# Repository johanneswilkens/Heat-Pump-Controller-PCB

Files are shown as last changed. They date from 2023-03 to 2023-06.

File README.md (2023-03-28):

# Heat Pump Controller PCB

This project is a versatile controller board designed primarily for LG Therma V heat pumps, but it may work with other systems as well. With Modbus and OpenTherm slave support, PWM input and output for a waterpump, multiple relays, and several input/output options, this board can help make the heat pump more efficient and make it easy to adjust heating curves and other settings.

This board can be programmed using the Arduino IDE or EspHome, which makes it easy to integrate with home automation systems like Home Assistant. With some modifications, the following code can run on it: https://github.com/altrnate32/esp-lg-control

In addition to the base features, this board includes several optional features, such as an isolated I2C interface, isolated UART, 5V UART, onboard temperature and humidity sensors, and a status LED. With these optional features, this board can be customized to suit a wide range of applications.

## Features

The following features are included in this controller board:

- Modbus and OpenTherm slave support
- PWM input and output for a waterpump
- 4 relays (can operate 230V AC 3A. For higher current, up to 10A PCB tracks must be reinforced with soldered on wire of sufficient cross section)
- 2 outputs that can work as high-side or low-side switches at 5V or 12V (via on board voltage converters)
- 2 inputs supporting 5V or 12V
- 4 connectors for DS18B20 sensors (several sensors can be connected to one connector)
- Optional isolated I2C interface
- Optional isolated UART
- Optional 5V UART
- Optional onboard DS18B20 and SHT40 sensor
- WS2812 LED for showing status (or regular LED if you dont need RGB)
- Powered via USB-C

## Project Status
- [x] Tested stable operation. 
- [x] Tested with LG Therma V HM143MR.U34 (14 kW three phase monoblock)
- [ ] Test on other devices
- [ ] Modify PCB for release
- [ ] Create Wiki Page

## Getting Started

To get started with this controller board, follow these steps:

1. Obtain the PCB files from the GitHub repository.
2. Use a PCB manufacturing service to manufacture the board or assemble the board yourself by soldering the components onto the board.
3. Program the ESP32 microcontroller using the Arduino IDE or other compatible software, such as Esphome. If you want to control your heat pump with Home Assistant, you can use Esphome to easily integrate the controller with Home Assistant.
4. Connect the heat pump components and other pheripherals to the appropriate connectors on the board. Make sure you use the correct connectors.
5. Power on the board using a USB-C cable.

## IO reference

| Function | ESP32 GPIO Pin |
|---|---|
| Input1 | GPIO36 |
| Input2 | GPIO39 |
| Output1 | GPIO25 |
| Output2 | GPIO26 |
| Relay1 | GPIO27 |
| Relay2 | GPIO14 |
| Relay3 | GPIO12 |
| Relay4 | GPIO13 |
| Pump PWM In | GPIO35 |
| Pump PWM Out | GPIO32 |
| Open Therm In | GPIO34 |
| Open Therm Out | GPIO33 |
| Modbus RX | GPIO16 |
| Modbus TX | GPIO17 |
| Modbus Flow Control | GPIO5 |
| LED | GPIO23 |
| DS18B20 | GPIO15 |
| UART_ISO RX | GPIO19 |
| UART_ISO TX | GPIO18 |
| UART_5V RX | GPIO2 |
| UART_5V TX | GPIO4 |
| I2C SDA | GPIO21 |
| I2C SCL | GPIO22 | 

## Donating

If you find this project useful and would like to support its development, you can donate to the project using [the Ko-fi donating platform](https://ko-fi.com/johanneswilkens). Your donation will help cover the costs of developing and testing the board, as well as maintaining the project repository and providing support to users.



## Support and feedback

If you need help with this project, or have any suggestions, please open an issue on the GitHub repository.

## License

This work is licensed under a
[Creative Commons Attribution-NonCommercial-ShareAlike 4.0 International License][cc-by-nc-sa].

[][cc-by-nc-sa]

[cc-by-nc-sa]: http://creativecommons.org/licenses/by-nc-sa/4.0/
[cc-by-nc-sa-image]: https://licensebuttons.net/l/by-nc-sa/4.0/88x31.png
[cc-by-nc-sa-shield]: https://img.shields.io/badge/License-CC%20BY--NC--SA%204.0-lightgrey.svg

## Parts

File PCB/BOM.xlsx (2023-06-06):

Designator | Footprint | Quantity | Value | Example LCSC Part #
C1, C2, C21, C23, C24, C5, C6, C7, C9 | 0603 | 9 | 100nF | C77055
C10, C14, C18, C20 | 0805 | 4 | 22uF | C86816
C11, C13, C19 | 1206 | 3 | 100uF | C312983
C12, C4 | 0805 | 2 | 10uF | C84416
C15 | 0603 | 1 | 8.2nF | C469537
C16 | 0603 | 1 | 10pF | C470847
C17 | 0603 | 1 | 1nF | C77026
C22, C3 | 0805 | 2 | 1uF | C77083
C8 | 0603 | 1 | 4.7nF | C85980
D1 | SOT-23 | 1 | SM712_SOT23 | C5180237
D10 | SOT-23 | 1 | BAT54W | C5261070
D11, D12, D4, D5 | D_SOD-123 | 4 | 1N4448W | C64898
D13 | LED_WS2812B-2020_PLCC4_2.0x2.0mm | 1 | WS2812-2020 | C965555
D14, D15, D16, D17, D18, D19, D20, D21, D22, D23, D7, D2 | 0603 | 12 | LED | C72041
D6, D8, D9 | D_SMA | 3 | SS34 | C2836396
F2 | 1206 | 1 | Polyfuse 0.75A holding - 1.5A trip | C269117
J1, J10, J11, J12, J19, J22, J23, J7, J8, J9 | KF141V-2.54-3P | 10 | KEFA KF141V-2.54-3P | C475115
J14, J15, J16 | JST_XH_B4B-XH-A_1x04_P2.50mm_Vertical | 3 | JST XH B4B | C144395
J17, J18, J3, J4 | KF142V-5.08-3P | 4 | KEFA KF142V-5.08-3P | C475135
J2 | USB_C_Receptacle_HRO_TYPE-C-31-M-12 | 1 | USB_C_Receptacle | C2988369
J6 | KF141V-2.54-2P | 1 | KEFA KF141V-2.54-2P | C475114
K1, K2, K3, K4 | Relay_SPDT_SANYOU_SRD_Series_Form_C | 4 | SONGLE SRD-05VDC-SL-C | C30431
L1, L3 | L_Bourns_SRP7028A_7.3x6.6mm | 2 | 22uH | C5189963
L2 | L_Bourns-SRN8040_8x8.15mm | 1 | 3.6uH | C168119
Q1 | SOT-363_SC-70-6 | 1 | UMH3N | C62892
Q10, Q11, Q12, Q13, Q19, Q2, Q20, Q22, Q3, Q5, Q8 | SOT-23 | 11 | BC847 | C426568
Q14, Q21, Q4, Q6, Q7, Q9 | SOT-23 | 6 | BC857 | C5204724
R1, R3 | 0603 | 2 | 680R | C112310
R10, R17, R18, R19, R20, R35, R39, R4, R40, R41, R46, R47, R48, R49, R5, R52, R53, R6, R62, R63, R64, R67, R68, R69, R7, R70, R71, R8, R9, R23 | 0603 | 29 | 10k | C98220
R11, R27 | 0603 | 1 | 470R | C114669
R12, R13 | 0603 | 2 | 220R | C107696
R14, R15 | 0603 | 2 | 5k1 | C105580
R16 | 0603 | 1 | 1M | C105578
R2 | 0603 | 1 | 130R | C141677
R21, R28 | 0603 | 2 | 270k | C137754
R22, R32, R42, R43, R44 | 0603 | 5 | 4k7 | C99782
R24 | 0603 | 1 | 6k8 | C114632
R25 | 0603 | 1 | 36k | C114619
R26 | 0603 | 1 | 2k7 | C114612
R29 | 0603 | 1 | 15k | C114661
R30 | 0603 | 1 | 100r | C105588
R31 | 0603 | 1 | 39r | C137733
R33 | 0603 | 1 | 33k | C126359
R34, R45 | 0603 | 2 | 20k | C105575
R36 | 0603 | 1 | 1k | C22548
R37, R38, R50, R51, R65, R66 | 0603 | 6 | 47k | C105579
R54, R55, R56, R57 | 0603 | 4 | 820R | C114638
R58, R59, R60, R61, R72, R73, R74 | 0603 | 7 | 390R | C114620
SW1 | SW_SPST_SKQG_WithStem | 1 | TS-1187A-C-C-B | C318889
U1 | SOIC-8_3.9x4.9mm_P1.27mm | 1 | MAX3485 | C695837
U10 | VSSOP-8_2.4x2.1mm_P0.5mm | 1 | TXB0102DCU | C60709
U11 | SOIC-8_3.9x4.9mm_P1.27mm | 1 | ISO7721 | C366164
U12 | Sensirion_DFN-4_1.5x1.5mm_P0.8mm_SHT4x_NoCentralPad | 1 | SHT4x | C2909890
U13 | TO-92_Inline | 1 | DS18B20 | C376006
U2 | ESP32-WROOM-32 | 1 | ESP32-WROOM-32 | C701342
U3 | SOIC-16_3.9x9.9mm_P1.27mm | 1 | CH340C | C84681
U4 | SOT-23-6 | 1 | USBLC6-2SC6 | C5180249
U5, U7 | SOT-23-6 | 2 | MT3608 | C84817
U6 | TI_SO-PowerPAD-8_ThermalVias | 1 | TPS54331 | C9865
U8 | SOIC-8_3.9x4.9mm_P1.27mm | 1 | DS18B20Z | C695837
U9 | SOIC-8_3.9x4.9mm_P1.27mm | 1 | ISO1540 | C179739

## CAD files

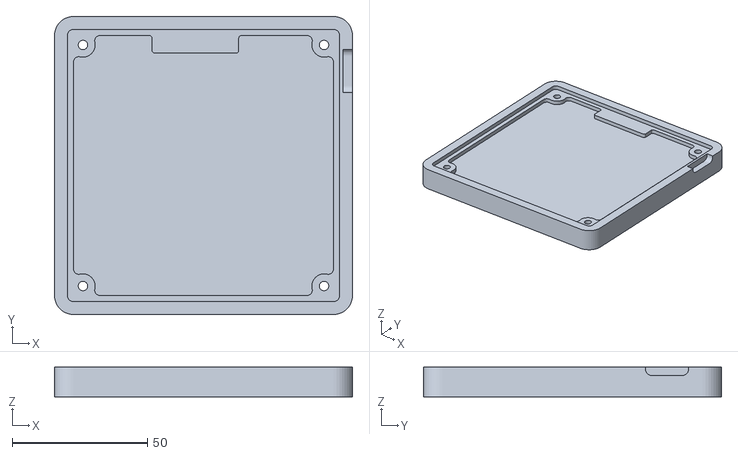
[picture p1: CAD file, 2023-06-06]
Case/Basic case.stl
110.0 x 110.0 x 11.0

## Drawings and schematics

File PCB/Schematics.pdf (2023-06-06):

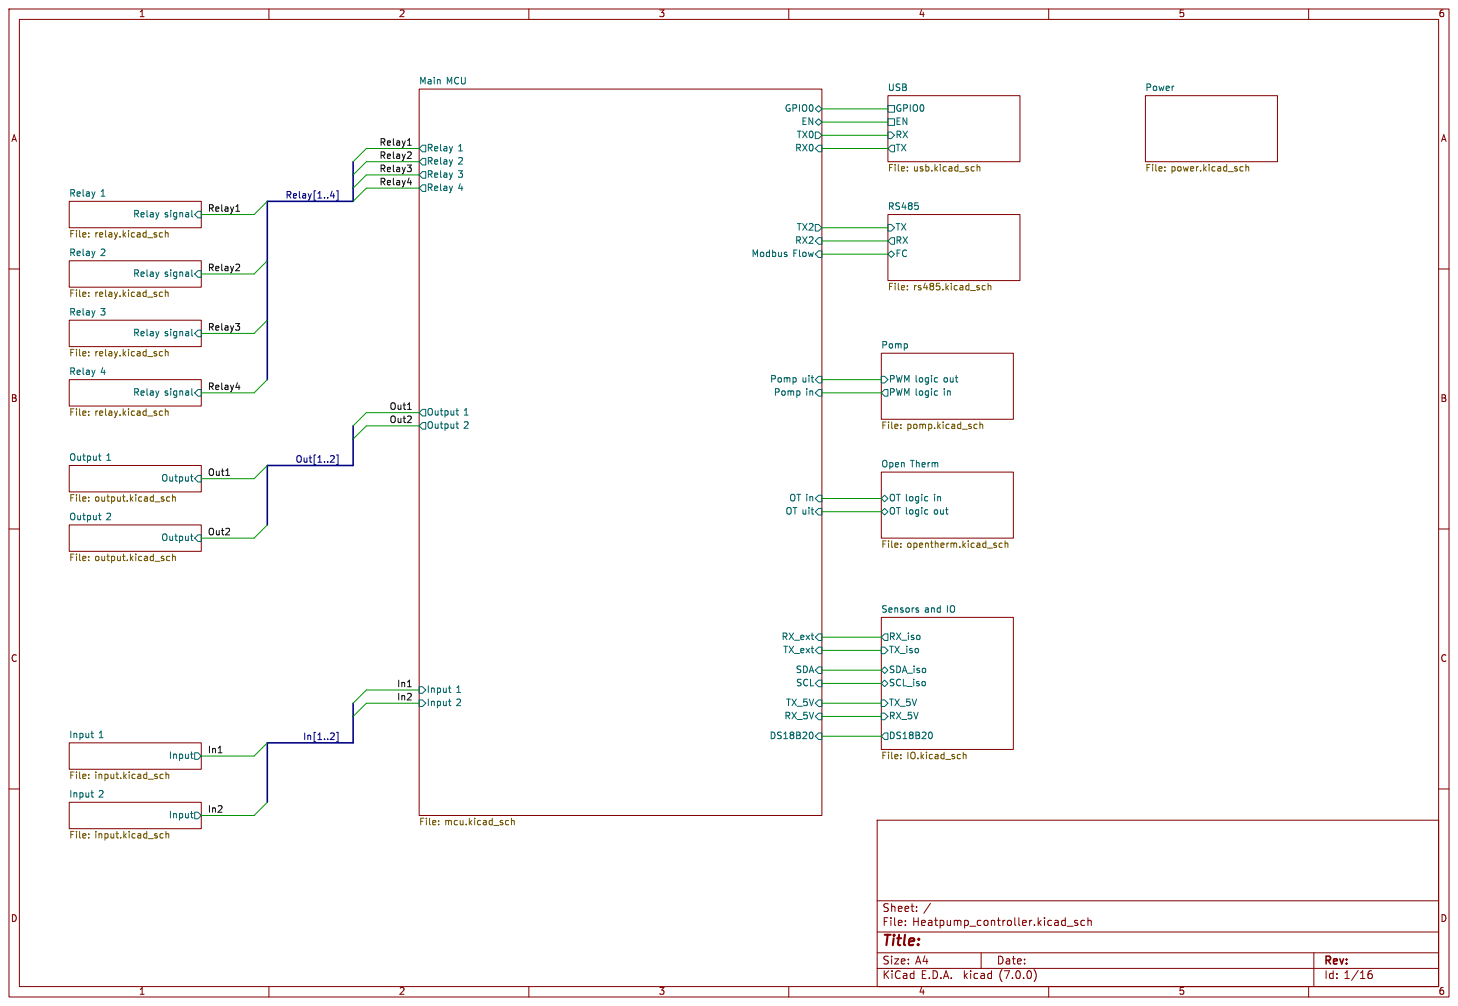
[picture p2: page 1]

Power File: power.kicad_sch EN

TX0 GPIO0 RX0 TX2 RX2 Relay 2 Relay 1 Relay 3 Relay 4 Output 1 Output 2

Pomp in OT uit OT in Pomp uit DS18B20 TX_ext RX_ext RX_5V

Id: 1/16 Title: File: Heatpump_controller.kicad_sch Sheet: /

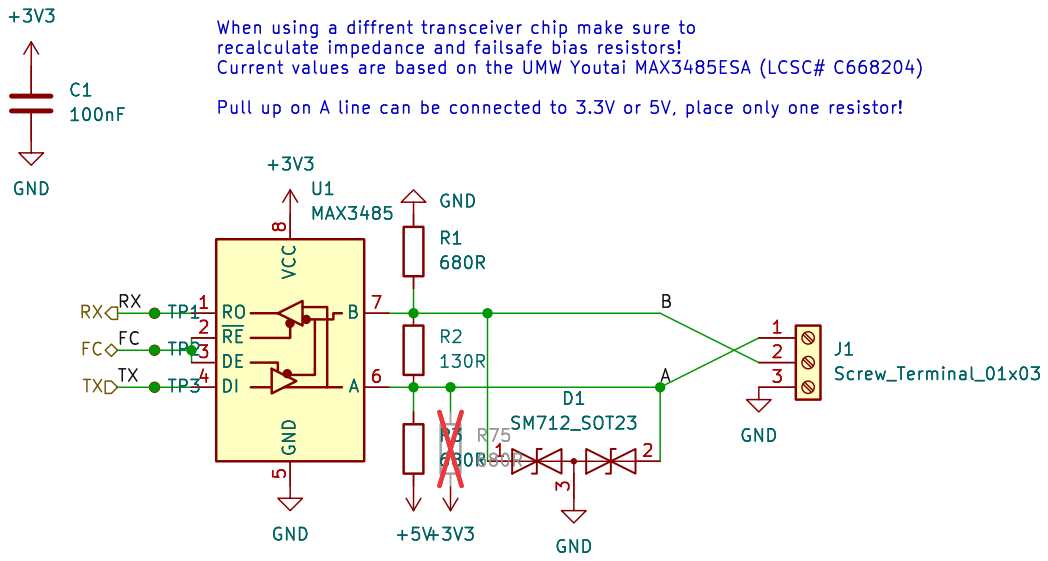
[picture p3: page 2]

Id: 2/16 Title: File: rs485.kicad_sch Sheet: /RS485/ GND

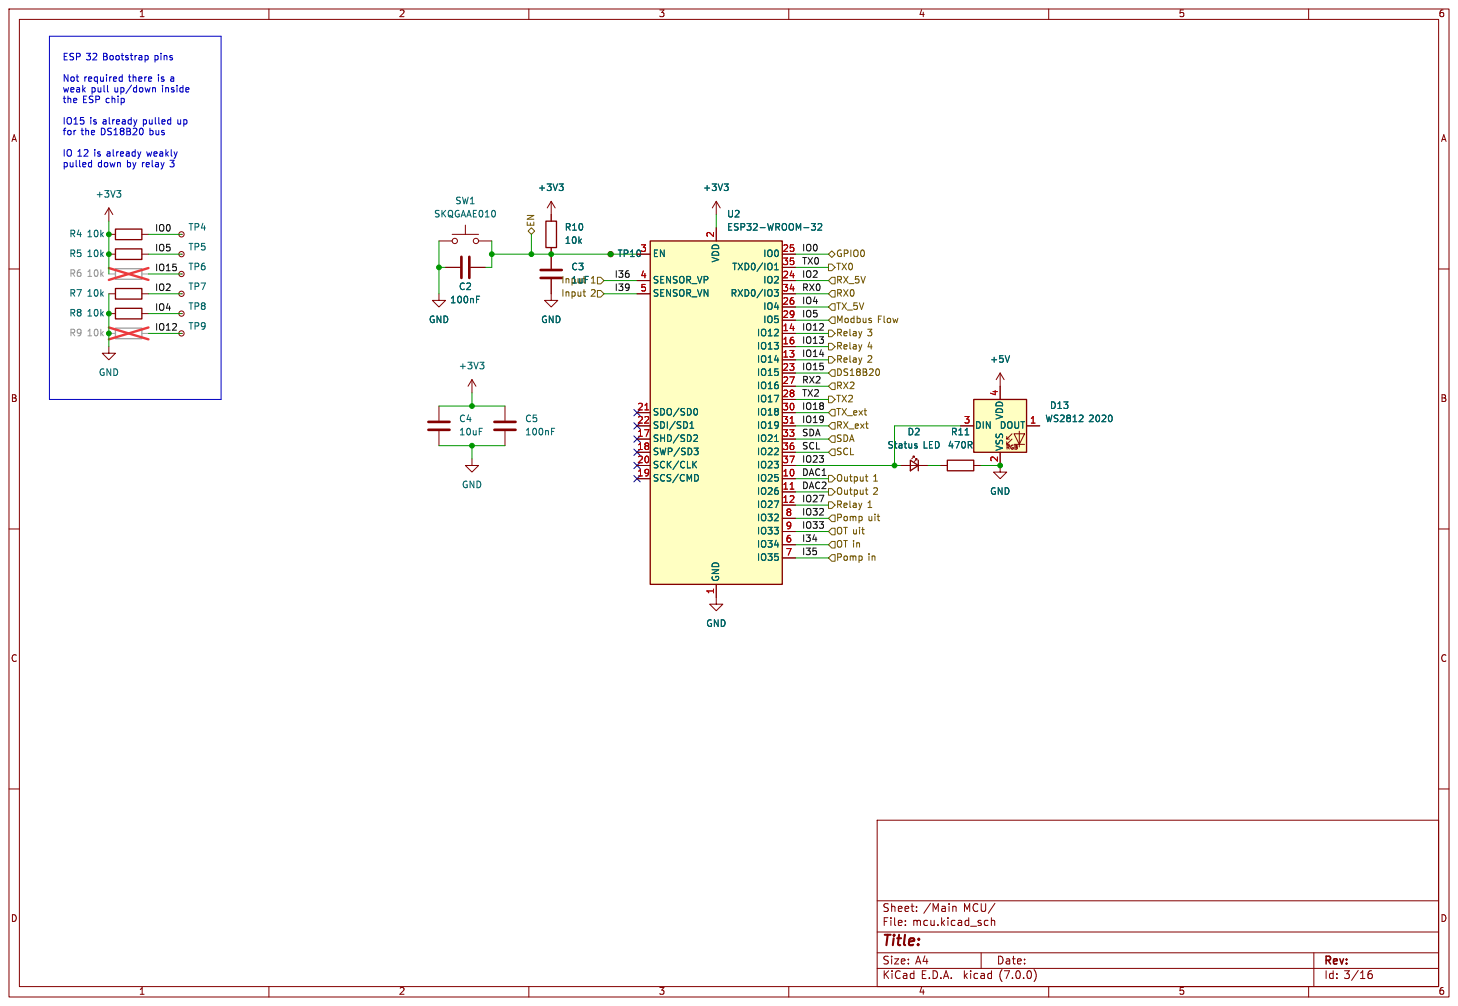
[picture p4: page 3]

IO15 is already pulled up
for the DS18B20 bus

IO 12 is already weakly

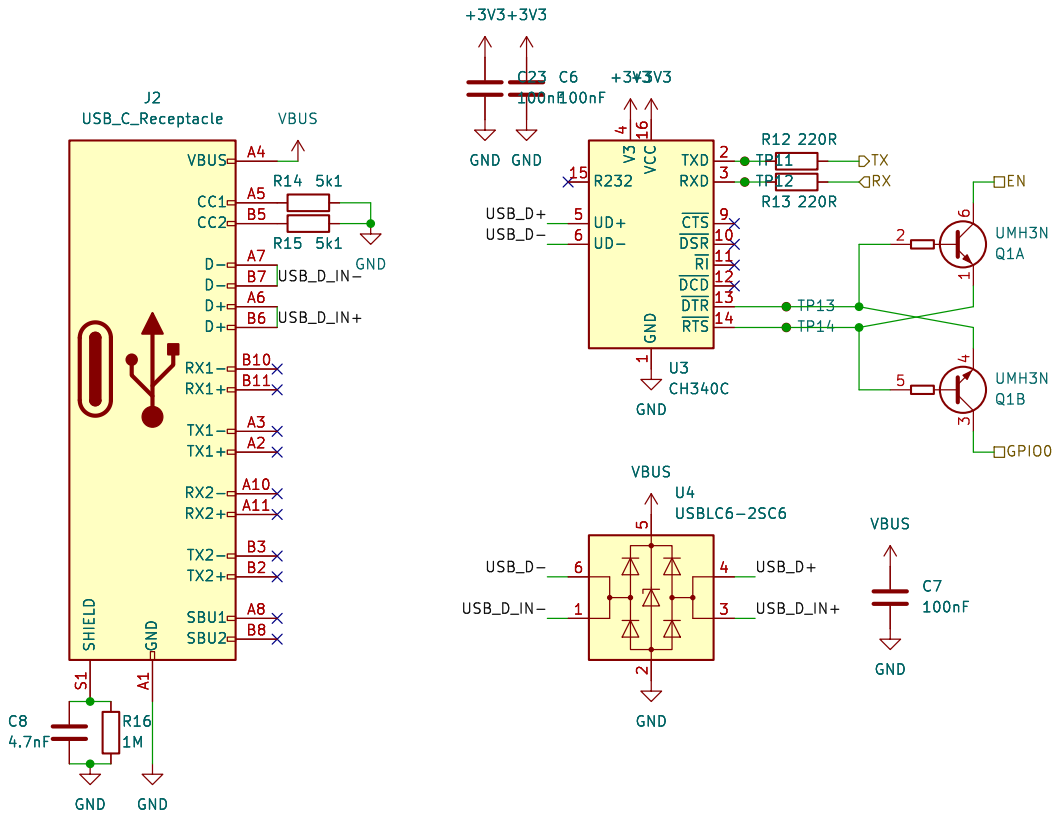
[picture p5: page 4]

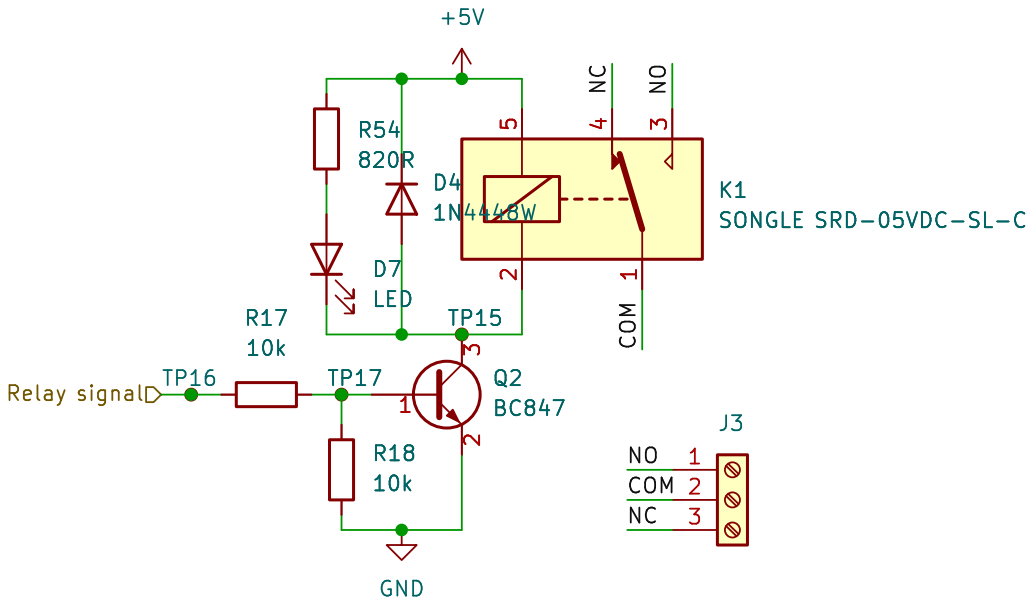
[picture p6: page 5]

Id: 5/16 Title: File: relay.kicad_sch Sheet: /Relay 1/ GND

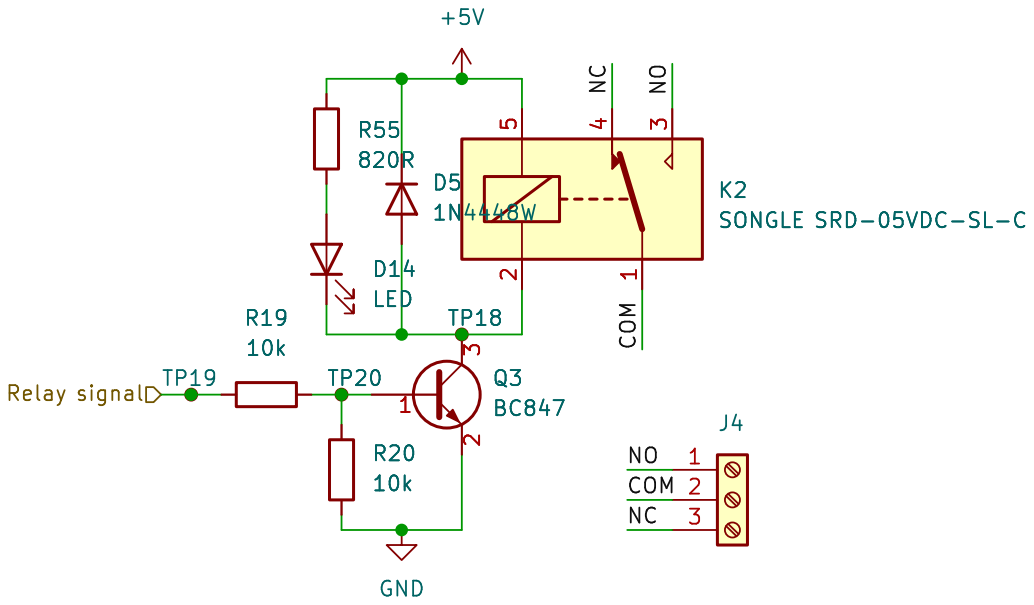
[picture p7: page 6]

Id: 6/16 Title: File: relay.kicad_sch Sheet: /Relay 2/ GND

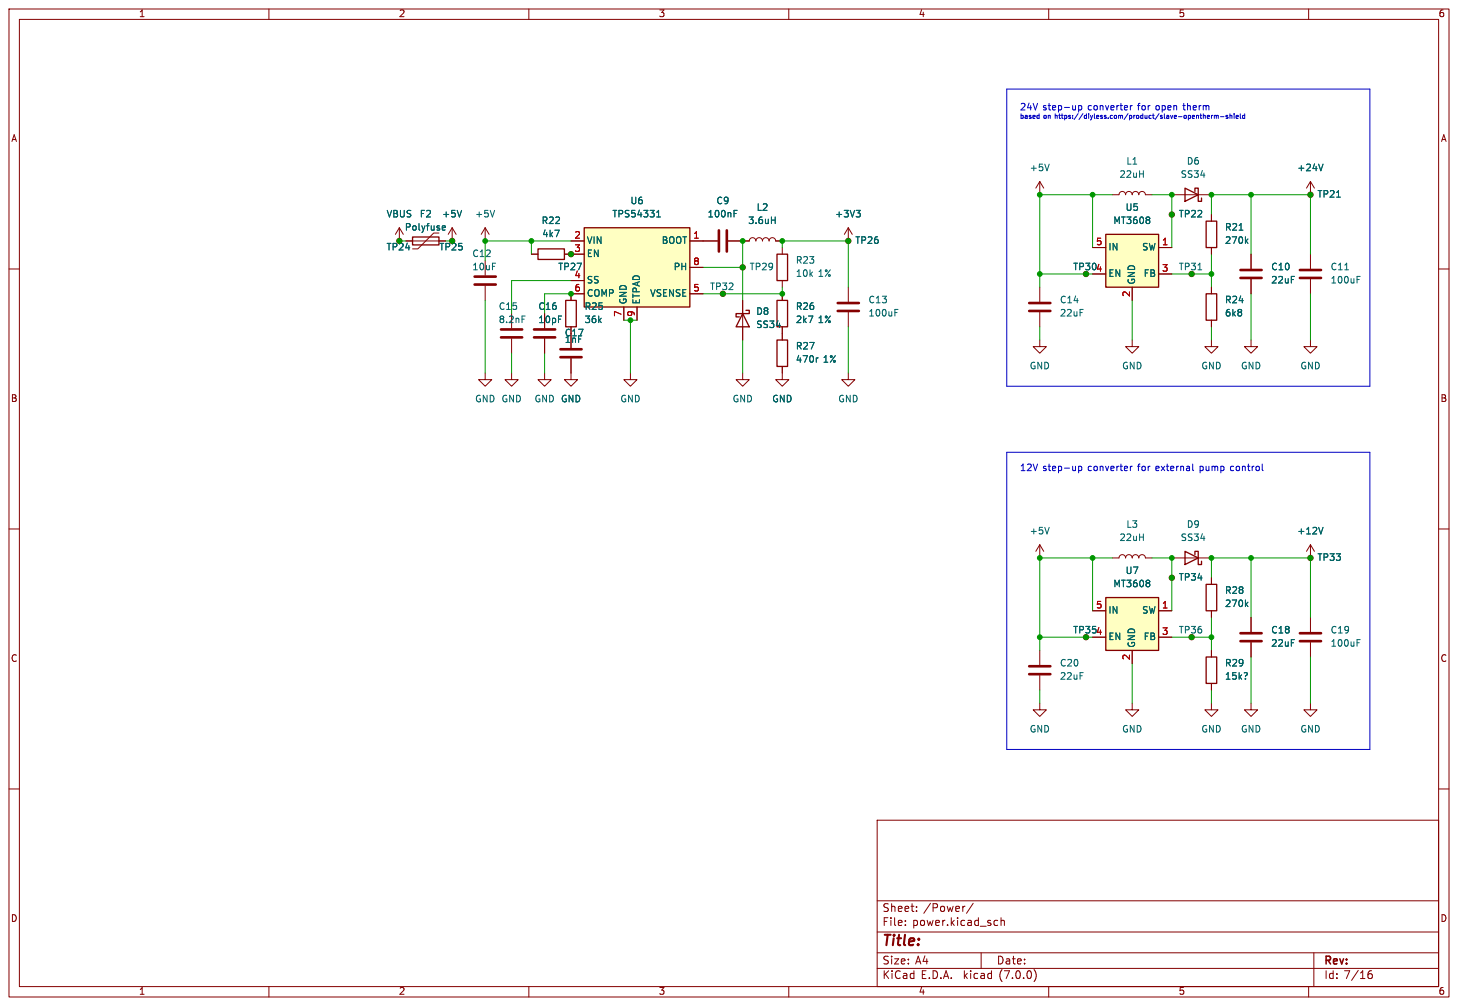
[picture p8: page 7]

^{based on https://diyless.com/product/slave-opentherm-shield} C10

Id: 7/16 Title: File: power.kicad_sch Sheet: /Power/

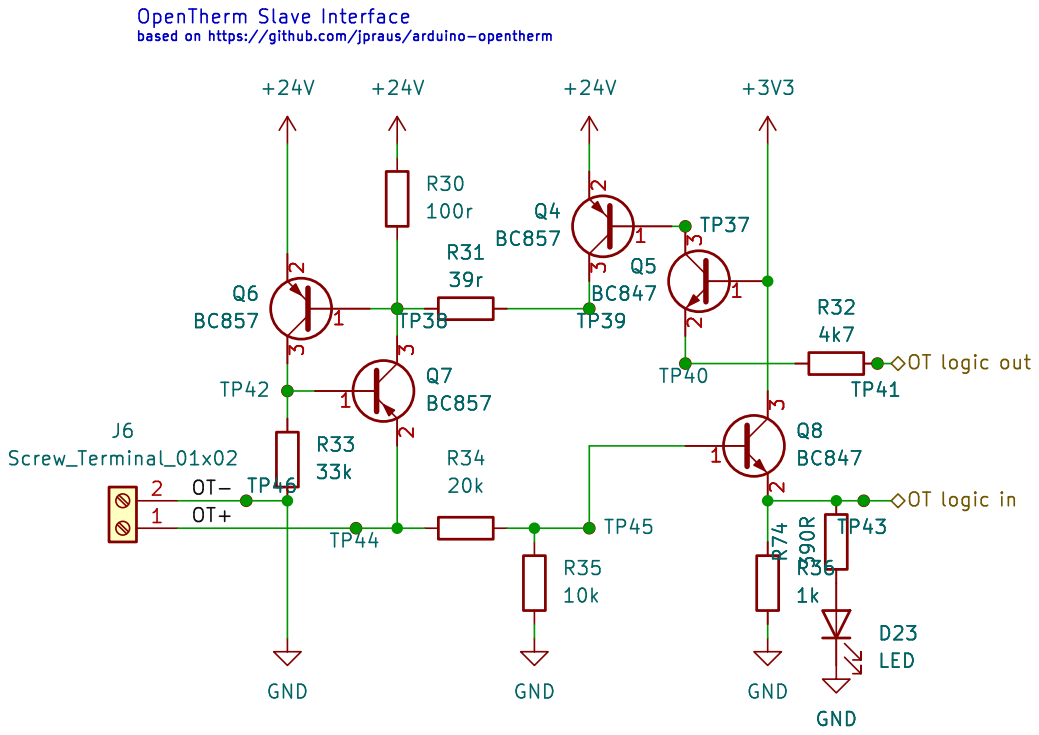
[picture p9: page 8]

2 3 Q7 BC857 OT logic in OT logic out OT- OT+ OpenTherm Slave Interface

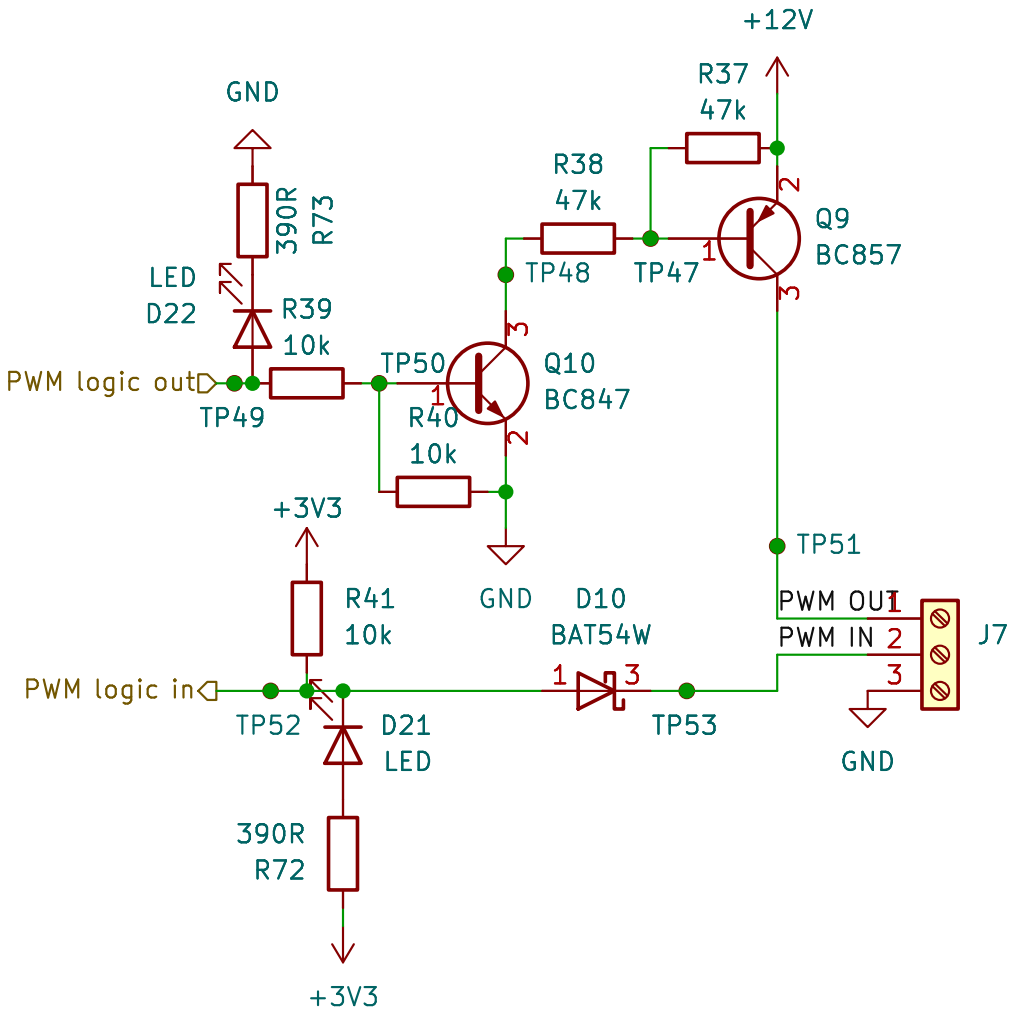
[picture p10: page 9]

Id: 9/16 Title: File: pomp.kicad_sch Sheet: /Pomp/ TP51 R41

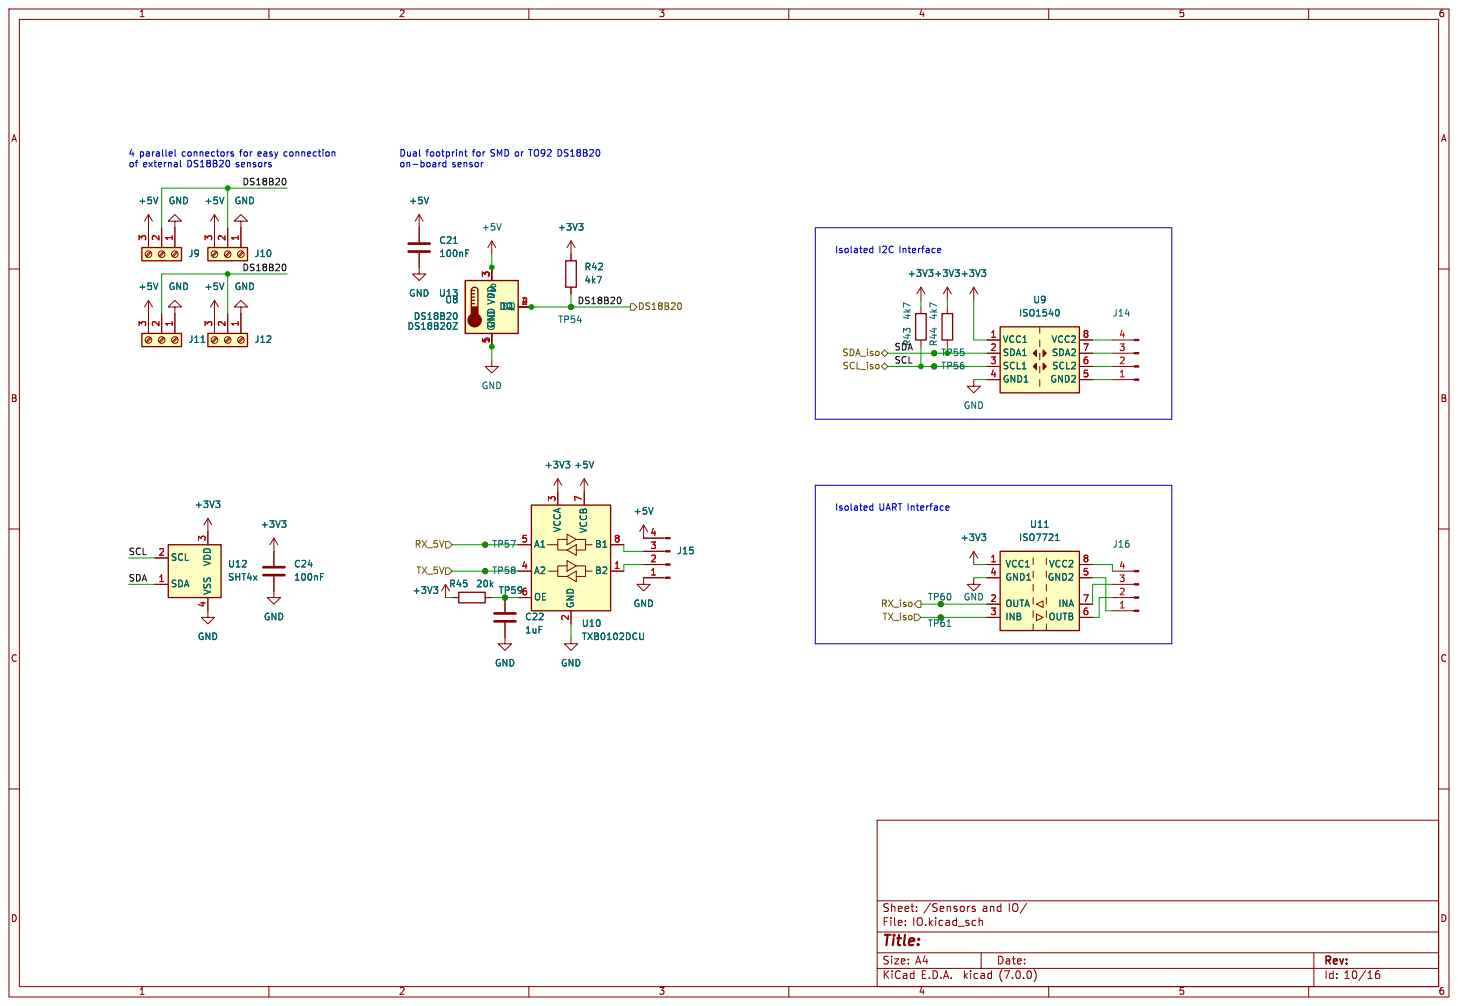
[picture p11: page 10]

1 DQ 2 V_{DD} 3 GND U8 DS18B20Z VDD DQ 4 GND

1 DQ 2 V_{DD} 3 U13 DS18B20 GND VDD DQ 4 GND

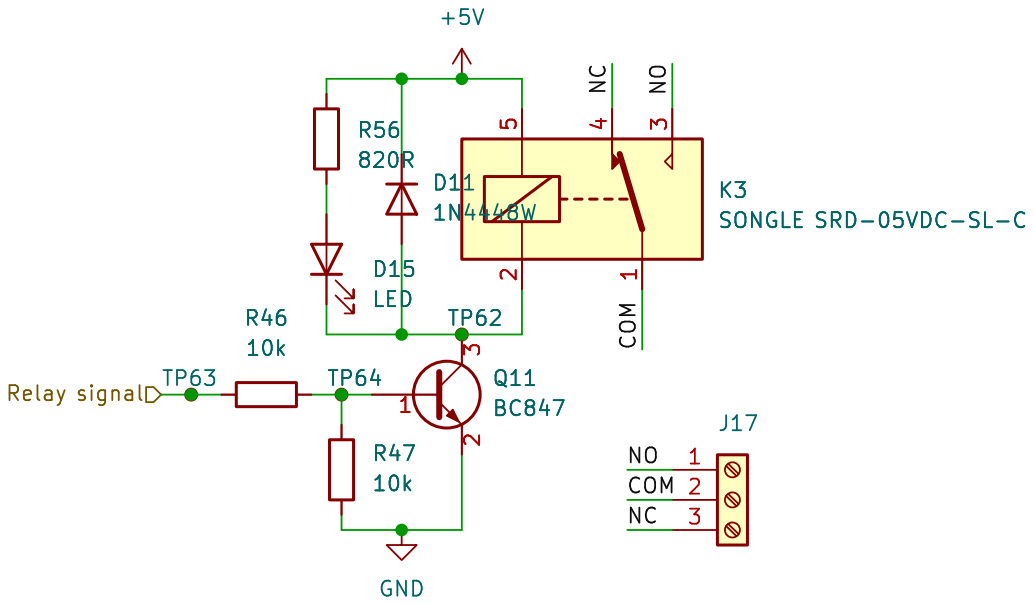
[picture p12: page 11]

Id: 11/16 Title: File: relay.kicad_sch Sheet: /Relay 3/ GND

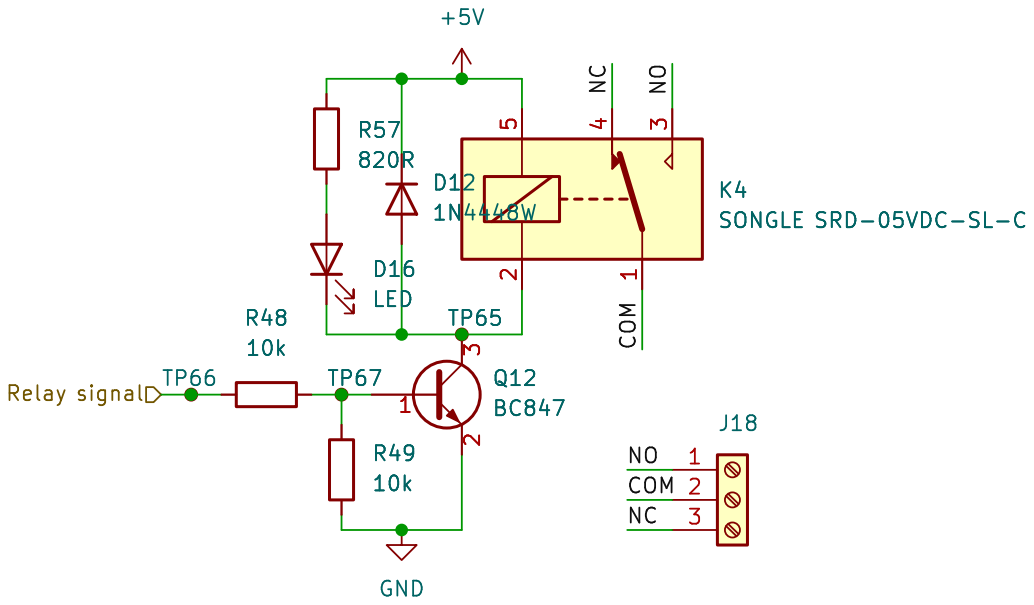
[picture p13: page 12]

Id: 12/16 Title: File: relay.kicad_sch Sheet: /Relay 4/ GND


Components in box are only required when using output as high a side switch GND OUT VCC


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
